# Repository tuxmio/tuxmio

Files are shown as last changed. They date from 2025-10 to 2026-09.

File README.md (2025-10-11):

## Hi there 👋
This project was started to combine industrial controllers, open-source controllers, and the freedom of customization.

1. Project Name & Description
   
    TUXMIO= 2XMIO=MIO+MIO=Make It Own Modular Input/Output System
TUXMIO is a customizable Modular Input/Output System. It allows users to mix and match hardware while keeping full control over their automation systems.

2. Features
   
    ✔ Modular Design – Easily expand and customize I/O modules based on project needs.
  
    ✔ Hybrid Compatibility – Works with both industrial controllers (PLC, DCS) and open-source hardware (Arduino, ESP32, Raspberry Pi).
  
    ✔ Cross-Platform Support – Works with Linux, Windows, and embedded systems.
  
    ✔ Industrial-Grade Reliability – Designed for rugged environments with robust protection features.
  
    ✔ Flexible Manufacturing Options – Users can build it themselves, order custom production, or buy pre-assembled modules.

3. Installation & Setup
   
    Hardware:
  
    ✔ Choose your favorite open-source controller
  
    ✔ Connect it to TUXMIO
  
    ✔ Enjoy your controller in an industrial environment
  
    Software & Setup:
  
    Use your usual tools for firmware installation, configuration, and testing—just like you always do!

4. Usage

    After setup, just start your system and enjoy your creation.

5. Hardware Requirements

    ✔ Choose your favorite open-source controller (Arduino, Raspberry Pi, ESP32, etc.).
   
    ✔ TUXMIO modules (customize based on your needs).
   
    ✔ You can prepare your own power supply voltages, or use the TUXMIO PS board for convenience.
   
    ✔ Any additional sensors, actuators, or peripherals based on your project.

6. Contributing

    Hey, I’m not a professional in electronics, 3D design, or prototyping, so please be understanding and forgiving if you spot any mistakes or discrepancies. 😊
   
    If you’d like to help out, here’s how you can contribute:
   
      ✔ Fork the Repo: Feel free to fork this repo and create a branch with your changes.
   
      ✔ Submit a Pull Request: When you're ready, send over a pull request!
   
      ✔ Report Issues: If you notice any bugs or have suggestions, don’t hesitate to open an issue.
   
      ✔ Join the Fun: Let’s work together to make this project better and take it to new heights!

7. License
   TUXMIO is proudly open in both mind and design.
All software and firmware are shared under the MIT License — free to use, modify, and remix however you like.
All hardware designs (schematics, PCBs, 3D models) follow the CERN Open Hardware License – Permissive v2.0, allowing you to build, improve, and even sell your own versions, as long as you keep the original attribution intact! 😊

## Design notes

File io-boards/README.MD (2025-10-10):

┌──────┬────────────┬───────────┬─────────────────────────────────────────────┬───────────────────────────────────────────────────────────────────────────────┐
│ Code │ Complexity │ Priority  │ Description                                 │ Notes                                                                         │
├──────┼────────────┼───────────┼─────────────────────────────────────────────┼───────────────────────────────────────────────────────────────────────────────┤
│ DI   │ 0          │ 1         │ Direct digital input (NPN/PNP stabilized)   │ Simple design, direct to MCU or buffer input.                                 │
│ DI   │ 4          │ -         │ Differential digital input (super-fast OC)  │ High-speed differential inputs, open-collector tolerant.                      │
│ DI   │ 2          │ -         │ Optocoupled digital input (NPN/PNP)         │ Isolated voltage sensing, moderate complexity.                                │
│ DO   │ 0          │ 1         │ Direct digital output (NPN/PNP stabilized)  │ Transistor-based output, low-side/high-side variants possible.                │
│ DO   │ 2          │ -         │ Optocoupled digital output (short-prot.)    │ Protected, diagnostic LEDs, block on short.                                   │
│ DO   │ 4          │ -         │ Super-fast optocoupled digital output       │ High-speed driver, isolation + diagnostics.                                   │
│ DO   │ 4          │ -         │ Differential digital output (OC)            │ Fast differential output, open-collector style.                               │
│ DO   │ 1          │ 2         │ Relay output                                │ Mechanical relay, user-changeable type.                                       │
│ DO   │ 1          │ 2         │ SSR relay output                            │ Solid State Relay variant.                                                    │
│ AI   │ 0          │ 1         │ Direct analog input 0–5V                    │ Basic ADC interface.                                                          │
│ AI   │ 1          │ -         │ 0–10V analog input                          │ Most common industrial input range.                                           │
│ AI   │ 2          │ -         │ ±10V analog input                           │ Bipolar measurement range.                                                    │
│ AI   │ 4          │ 5         │ 0–5mA analog input                          │ Requires precise current sensing, maybe external supply.                      │
│ AI   │ 4          │ 5         │ 0–20mA analog input                         │ Current loop sensing, possibly needs shunt resistor.                          │
│ AI   │ 4          │ 5         │ Low-voltage 0–10mV analog input             │ For small-signal sensors, instrumentation amp required.                       │
│ AI   │ 3          │ 5         │ Thermocouple input                          │ Requires CJC, precision ADC, low noise.                                       │
│ AI   │ 3          │ 5         │ RTD input (PT100/PT1000)                    │ Requires excitation and bridge measurement.                                   │
│ AO   │ 0          │ 1         │ Direct analog output 0–5V                   │ Simple DAC output.                                                            │
│ AO   │ 2          │ 2         │ 0–10V analog output                         │ Standard industrial output range.                                             │
│ AO   │ 2          │ 5         │ ±10V analog output                          │ Bipolar DAC driver, requires dual supply.                                     │
│ AO   │ 4          │ 3         │ 0–20mA analog output                        │ Current loop output, supply-dependent.                                        │
└──────┴────────────┴───────────┴─────────────────────────────────────────────┴───────────────────────────────────────────────────────────────────────────────┘

Enhanced I/O Function Table with ABC Codes
#	Old Code	New Code	Description	Notes / Feature keywords
1	DI	DID	Direct Digital Input (NPN/PNP stabilized)	simplest form, direct connection
2	DI	DIF	Differential Digital Input (superfast OC)	high-speed, open-collector compatible
3	DI	DIO	Optocoupled Digital Input (NPN/PNP voltage)	isolated, standard industrial input
4	DO	DOD	Direct Digital Output (NPN/PNP stabilized)	simple transistor output
5	DO	DOO	Optocoupled Digital Output (short-prot, diag)	isolated, protected, LED indicators
6	DO	DOF	Fast Optocoupled Digital Output (superfast)	high-speed variant
7	DO	DOH	Differential (High-speed OC) Digital Output	OC differential drivers
8	DO	DOR	Relay Output (mechanical relays)	changeable relay sockets
9	DO	DOS	SSR Output (Solid-State Relay)	solid-state version
10	AI	AIV	Analog Voltage Input (0–5V, 0–10V, ±10V)	voltage-based measurement
11	AI	AIC	Analog Current Input (0–5mA, 0–20mA)	current loop or shunt measurement
12	AI	AIL	Low-Voltage / Millivolt Input	instrumentation, low-noise sensors
13	AI	AIT	Thermocouple Input	temperature, requires CJC
14	AI	AIR	Resistance / RTD Input (PT100/PT1000)	with excitation and linearization
15	AO	AOV	Analog Voltage Output (0–5V, 0–10V, ±10V)	DAC-based voltage output
16	AO	AOC	Analog Current Output (0–20mA)	current loop output
17	COM	CCI	Communication Interface Input (e.g., RS, CAN)	receives data
18	COM	CCO	Communication Interface Output	transmits data
19	COM	CCX	Communication Transceiver / Bidirectional	bidirectional (e.g., RS485, CAN, I²C)

1st letter: Domain
D → Digital
A → Analog
C → Communication

2nd letter: Direction
I → Input
O → Output
X → Bidirectional / mixed

3rd letter: Feature

D = Direct
O = Optocoupled
F = Fast / Differential
R = Relay
S = Solid State
V = Voltage
C = Current
L = Low voltage / millivolt
T = Thermocouple
R = RTD (resistance sensor)
H = High-speed / OC
X = Mixed / special

┌────────────┬───────────┬───────────────────────────────────────────────┐
│ Letter Pos │ Represents│ Example Letters / Meaning                     │
├────────────┼───────────┼───────────────────────────────────────────────┤
│ 1st        │ Domain    │ D = Digital, A = Analog, C = Communication    │
│ 2nd        │ Direction │ I = Input, O = Output, X = Bidirectional      │
│ 3rd        │ Feature   │ D = Direct, O = Optocoupled, F = Fast,        │
│            │           │ R = Relay, S = Solid-state, V = Voltage,      │
│            │           │ C = Current, L = Low-voltage, T = TC, R = RTD │
└────────────┴───────────┴───────────────────────────────────────────────┘

<ABC>-<LS>-<PT>-<RPO>-Vx.xx

where:
ABC = 3-letter functional code = [Domain][Direction][Feature]
    Domain: A = Analog, D = Digital (use “Digital”), C = Communication
    Direction: I = Input, O = Output, X = Bidirectional
    Feature: domain-specific (e.g. D=Direct, O=Optocoupled, F=Fast/Differential, R=Relay, S=SolidState, V=Voltage, C=Current, L=Low-voltage, T=Thermocouple, R=RTD, H=High-speed, X=Mixed)
LS = two digits: [LogicLevel][SocketType]
    LogicLevel (first digit): 3 = 3.3 V logic, 5 = 5 V logic, 9 = Mixed/Auto/Dual
    SocketType (second digit): 0 = Socket A, 1 = Socket B, 2 = Socket C, 3 = Socket D
PT = Peripheral Type (single letter)
    U = Voltage-type peripheral
    C = Current-type peripheral
RPO = Range code + Peripheral Option (two chars)
Range code (digit): Voltage codes (for U)
    0 = sink-mode NPN (logic sink)
    1 = 3.3/5 V logic-level field
    2 = 10 V
    3 = 12 V
    4 = 15 V
    5 = 24 V
    6 = 230 VAC
Range code (digit): Current codes (for C)
    0 = 0–5 mA
    1 = 0–20 mA
    2 = 4–20 mA
    3 = −20 mA … +20 mA
Peripheral Option (letter, immediately after range digit):
    N = Sink mode (NPN)
    P = Source mode (PNP)
    B = Bipolar
Vx.xx = Version (major.minor) e.g. V0.01

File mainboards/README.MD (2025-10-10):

TUXMIO Mainboard Classification
┌──────────────┬──────────────────────────────┬────────┬──────────────────────────────────────────────────────────────────────────────┐
│ Directory    │ Full Name                    │ Level  │ Description                                                                  │
├──────────────┼──────────────────────────────┼────────┼──────────────────────────────────────────────────────────────────────────────┤
│ L0-MB-PML    │ Power Management Layer       │ L0     │ Handles power entry, conversion, and protection (fuse, surge, polarity).     │
│              │                              │        │ Supplies regulated voltages to upper layers.                                 │
├──────────────┼──────────────────────────────┼────────┼──────────────────────────────────────────────────────────────────────────────┤
│ L1-MB-CIM    │ Controller Interface Module  │ L1     │ Hosts the main controller (MCU, SBC, or SoM). Manages logic, communication   │
│              │                              │        │ and links between the power and I/O layers.                                  │
├──────────────┼──────────────────────────────┼────────┼──────────────────────────────────────────────────────────────────────────────┤
│ L2-MB-IOP    │ Input/Output Peripherals     │ L2     │ Provides interface for I/O boards, sensors, and actuators. Includes sockets  │
│              │                              │        │ for I/O boards. each socket only supports specific I/O board types           │
└──────────────┴──────────────────────────────┴────────┴──────────────────────────────────────────────────────────────────────────────┘
 
   ┌┐   ┌┐   ┌┐   ┌┐   ┌┐   ┌┐   ┌┐   
   ||   ||   ||   ||   ||   ||   ||
   ||   ||   ||   ||   ||   ||   ||  ← I/O Boards
   ||   ||   ||   ||   ||   ||   ||
   └┘   └┘   └┘   └┘   └┘   └┘   └┘   
   ┌──────────────────────────────┐
   │  L2 – MB-IOP  (Peripherals)  │  ← I/O Expansion Layer
   └─────────────┬────────────────┘
                 │
   ┌─────────────┴────────────────┐
   │  L1 – MB-CIM  (Controller)   │  ← Processing & Communication Layer
   └─────────────┬────────────────┘
                 │
   ┌─────────────┴────────────────┐
   │  L0 – MB-PML  (Power)        │  ← Power & Protection Base Layer
   └──────────────────────────────┘

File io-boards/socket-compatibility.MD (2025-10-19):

Socket–Board compatibility is non-commutative.

> a board designed for Socket A may fit Socket B, but not necessarily vice-versa.

Final (refined) socket acronyms
#	Acronym	   Cards        Full Name	            Description
0	GPP	       DI/DO/AO     General Purpose Pin	    Multi-use socket — supports digital input/output and analog output. Default I/O connection.
1	AIP	       AI           Analog Input Pin	    Dedicated analog input socket for sensors (voltage, current, RTD, etc.).
2	URP	       Serial COM   UART Pin	            Serial communication socket — TX/RX pair for asynchronous data.
3	ICP	       I²C          I²C Pin	                Two-wire serial communication socket — SCL/SDA lines for intelligent peripherals.

Compatibility Matrix
┌───────────────┬─────┬─────┬─────┬─────┐
│ Board \ Socket│ GPP │ AIP │ URP │ ICP │
├───────────────┼─────┼─────┼─────┼─────┤
│ GPP           │  ✓  │  ✓  │  ✓  │  ✓  │
│ AIP           │     │  ✓  │     │  ✓  │
│ URP           │     │     │  ✓  │     │
│ ICP           │     │     │     │  ✓  │
└───────────────┴─────┴─────┴─────┴─────┘

🧩 Physical Connection System

All TUXMIO sockets and boards use 2.54 mm pitch pin header–type connectors for electrical and mechanical connection.
Sockets are equipped with female pin headers, while the I/O boards use corresponding male pin headers.
To ensure correct insertion and prevent incompatible combinations, certain holes in the socket connectors are mechanically blocked using plastic plugs, and matching pins are omitted on the corresponding boards.
This selective pin arrangement allows each board to fit only into its appropriate socket type, maintaining both electrical safety and system integrity.
Additionally, all connectors are polarized — boards cannot be inserted rotated 180°, preventing reverse connection or damage to components.For detailed socket–board relationships, For detailed socket–board relationships, please see the compatibility matrix.

Legend (for the table)
Sockets: o = empty hole, x = plugged hole
I/O Boards: - = pin present, x = pin absent

┌────────────┬───────────────────────┬───────────────────────────┬───────────────────────────┐
│            │                       │         Sockets           │        I/O Boards         │
│ Pin Number │ Function              ├──────┬──────┬──────┬──────┼──────┬──────┬──────┬──────┤
│            │                       │ GPP  │ AIP  │ URP  │ ICP  │ GPP  │ AIP  │ URP  │ ICP  │
├────────────┼───────────────────────┼──────┼──────┼──────┼──────┼──────┼──────┼──────┼──────┤
│ 1          │ IO pin to uC          │ o    │ o    │ o    │ o    │  -   │  -   │  -   │  -   │IO
│ 2          │ A_REF pin from uC     │ x    │ o    │ x    │ o    │  x   │  -   │  x   │  -   │A_Ref
│ 3          │ GND or GND1(seperated)│ o    │ o    │ o    │ o    │  -   │  -   │  -   │  -   │GND1
│ 4          │ N/A                   │ o    │ x    │ o    │ o    │  x   │  x   │  -   │  -   │N/A
│ 5          │ Diagnostics for future│ o    │ o    │ o    │ o    │  -   │  -   │  -   │  -   │Diag
│ 6          │ -10V bipolar          │ o    │ o    │ o    │ o    │  -   │  -   │  -   │  -   │-10V_b
│ 7          │   OV bipolar          │ o    │ o    │ o    │ o    │  -   │  -   │  -   │  -   │0V_b
│ 8          │ +10V bipolar          │ o    │ o    │ o    │ o    │  -   │  -   │  -   │  -   │+10V_b
│ 9          │ Not assigned yet      │ o    │ o    │ o    │ o    │  -   │  -   │  -   │  -   │N/A_Pin_9
│ 10         │ N/A                   │ x    │ x    │ o    │ x    │  x   │  x   │  -   │  x   │N/A
│ 11         │ +24VDC                │ o    │ o    │ o    │ o    │  -   │  -   │  -   │  -   │+24VDC
│ 12         │ GND from 24V          │ o    │ o    │ o    │ o    │  -   │  -   │  -   │  -   │GND_24V
└────────────┴───────────────────────┴──────┴──────┴──────┴──────┴──────┴──────┴──────┴──────┘

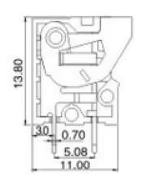
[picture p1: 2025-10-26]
accessories/Cover_for_terminal_KF141/KF141V.png

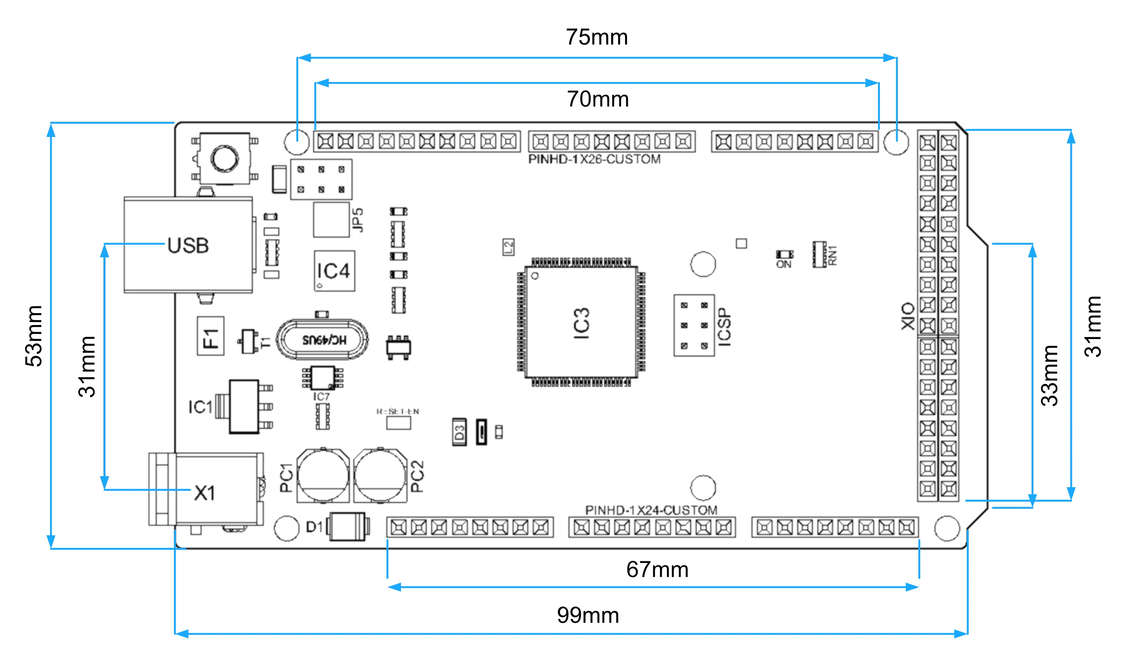
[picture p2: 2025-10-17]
datasheets/third-part/mega2560_dimmentions.png

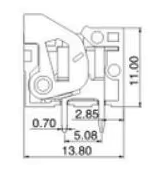
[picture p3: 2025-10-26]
accessories/Cover_for_terminal_KF141/KF141R.png

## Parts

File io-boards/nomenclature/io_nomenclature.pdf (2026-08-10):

Sheet1

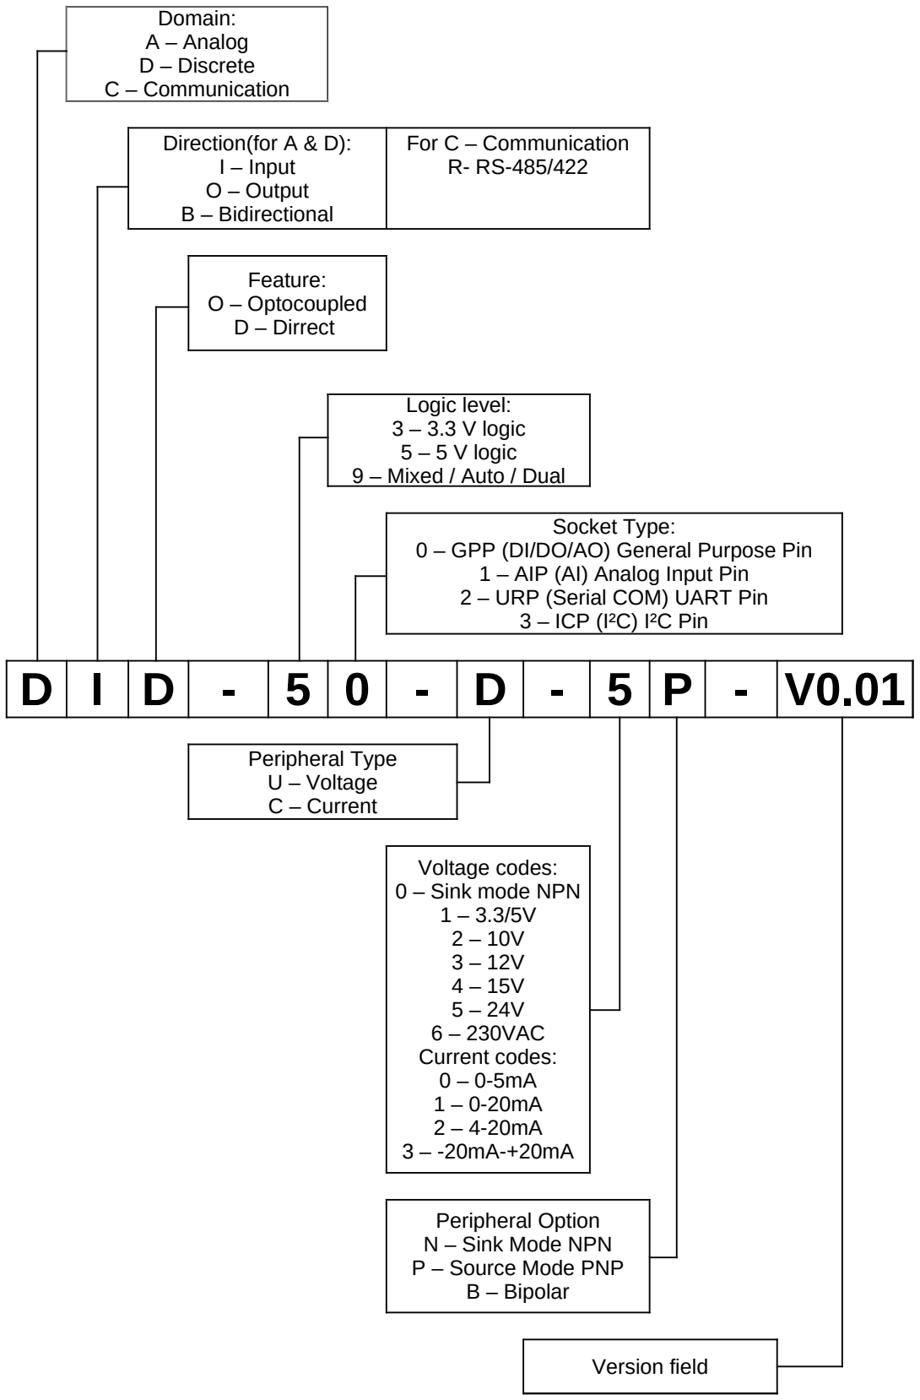
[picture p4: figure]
Version field; Domain: A – Analog D – Discrete C – Communication; Direction(for A & D): I – Input O – Output B – Bidirectional; For C – Communication R- RS-485/422; Feature: O – Optocoupled D – Dirrect; Logic level: 3 – 3.3 V logic 5 – 5 V logic 9 – Mixed / Auto / Dual; Socket Type: 0 – GPP (DI/DO/AO) General Purpose Pin 1 – AIP (AI) Analog Input Pin 2 – URP (Serial COM) UART Pin 3 – ICP (I²C) I²C Pin; Peripheral Type U – Voltage C – Current; Voltage codes: 0 – Sink mode NPN 1 – 3.3/5V 2 – 10V 3 – 12V 4 – 15V 5 – 24V 6 – 230VAC Current codes: 0 – 0-5mA 1 – 0-20mA 2 – 4-20mA 3 – -20mA-+20mA; Peripheral Option N – Sink Mode NPN P – Source Mode PNP B – Bipolar

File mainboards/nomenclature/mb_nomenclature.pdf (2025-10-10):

Sheet1

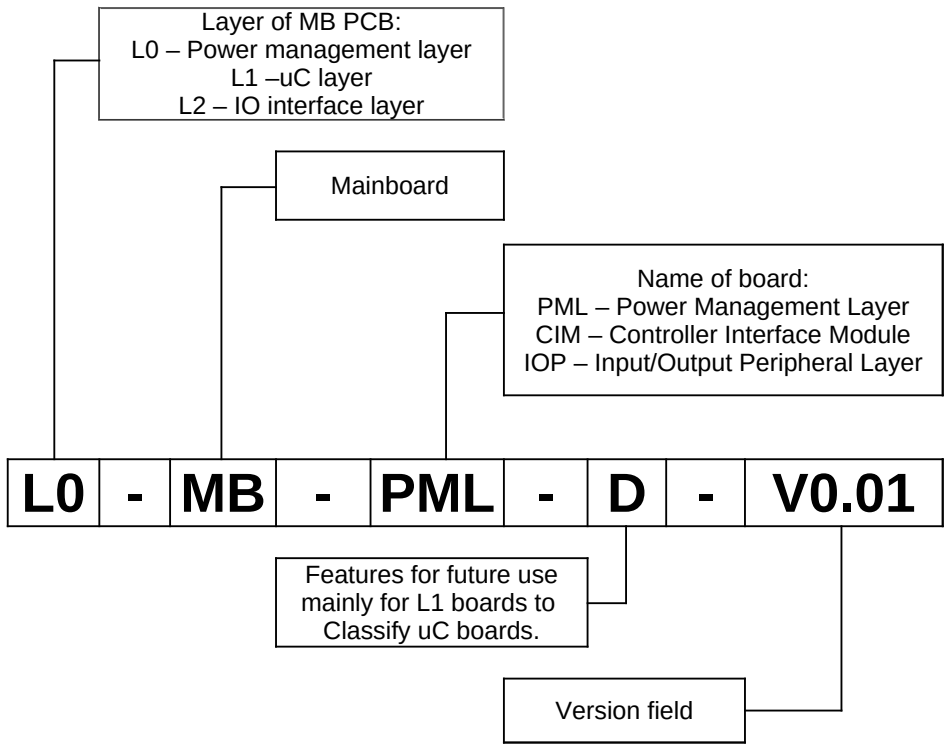
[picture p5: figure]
Mainboard; PML; Version field; Layer of MB PCB: L0 – Power management layer L1 –uC layer L2 – IO interface layer; Name of board: PML – Power Management Layer CIM – Controller Interface Module IOP – Input/Output Peripheral Layer; Features for future use mainly for L1 boards to Classify uC boards.

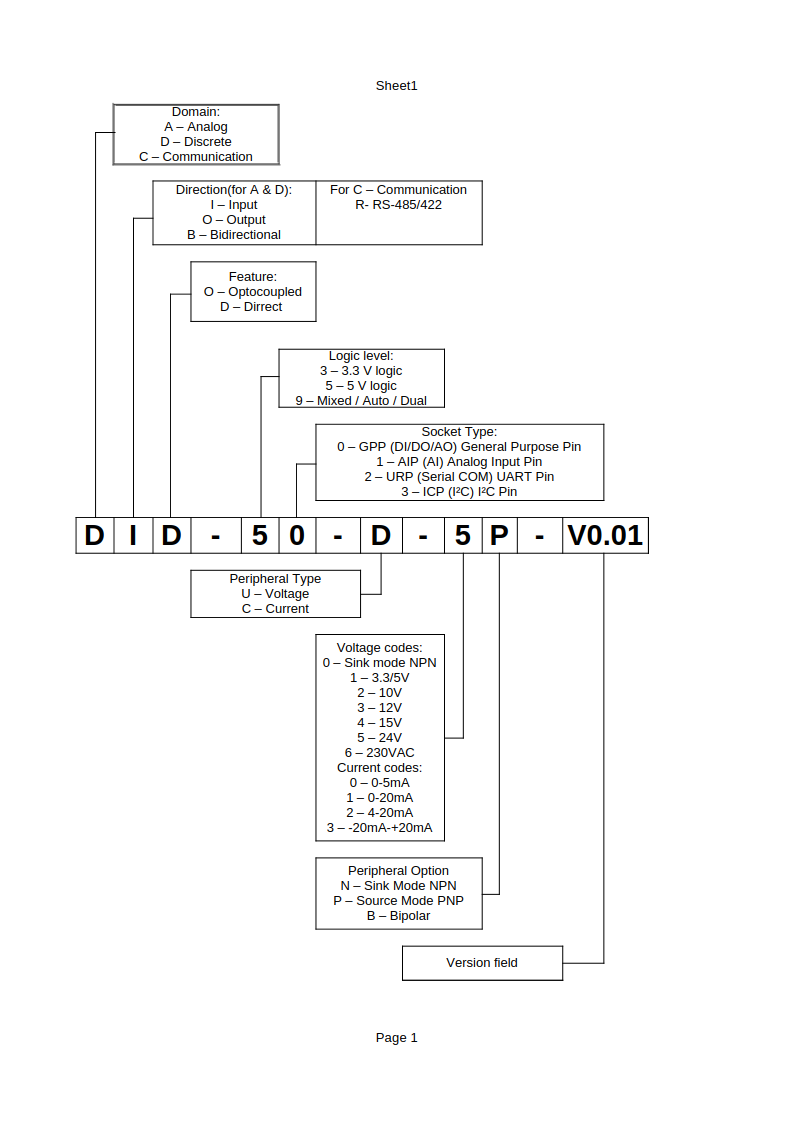
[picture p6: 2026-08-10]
io-boards/nomenclature/io_nomenclature.png

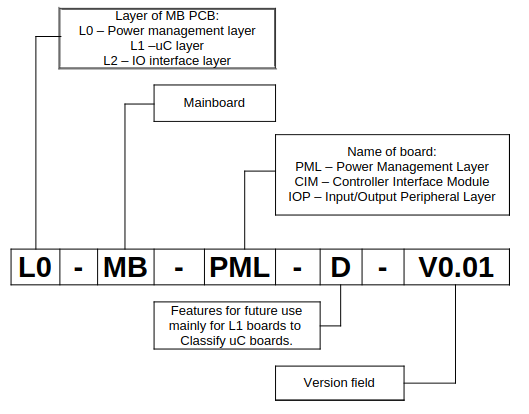
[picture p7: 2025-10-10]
mainboards/nomenclature/mb_nomenclature.png

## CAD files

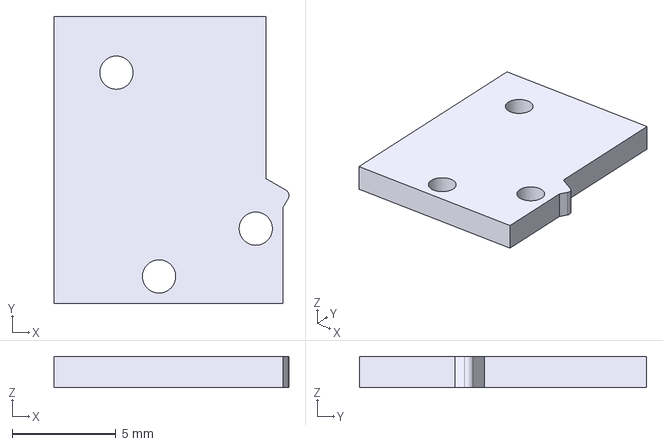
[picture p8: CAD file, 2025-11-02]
accessories/Cover_for_terminal_KF141/KF141_Cover.step
11.3 x 13.8 x 1.50 mm

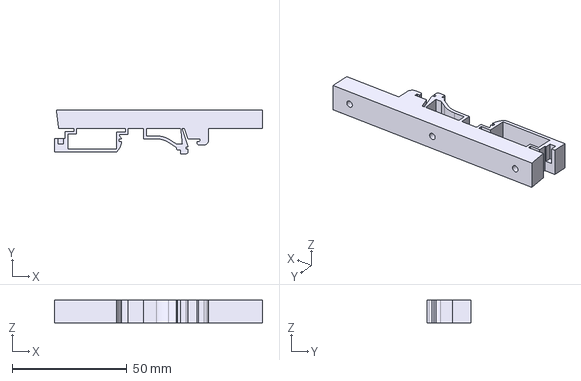
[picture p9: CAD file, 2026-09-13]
accessories/DIN_rail_PCB_adapter/PCB-adapter-90-edited-Body.step
90.8 x 19.0 x 10.0 mm

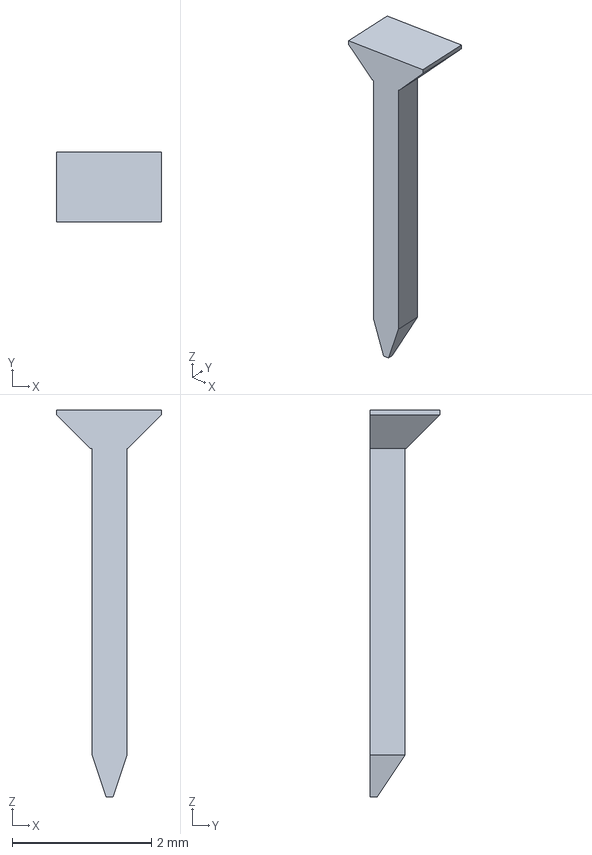
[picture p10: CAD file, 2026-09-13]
accessories/Pin_Plug/Plug.FCStd
1.50 x 1.00 x 5.55 mm

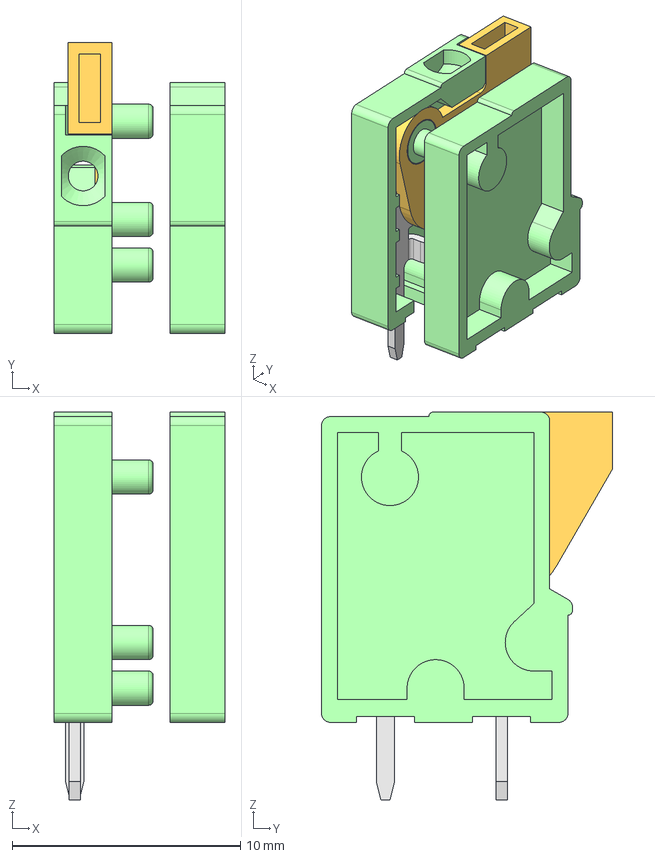
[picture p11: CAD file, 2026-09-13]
datasheets/third-part/FFKDS_V.FCStd
7.48 x 12.8 x 17.0 mm
Body(Cut)
Lever
Pin
EndPlate

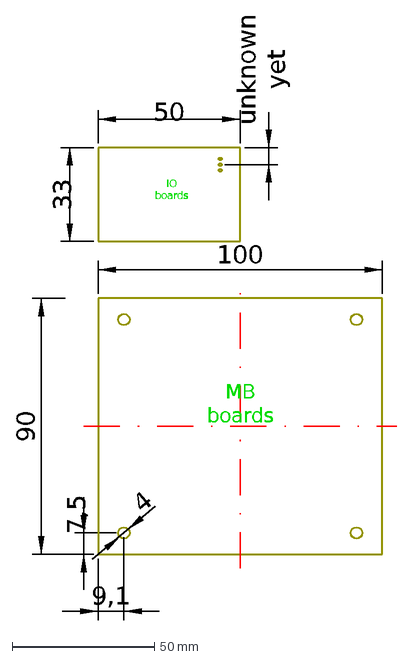
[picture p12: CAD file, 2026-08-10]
datasheets/tuxmio/Dimentions_of_boards.dxf
7,5
33
50
IO boards
unknown yet
100
4
9,1
90
MB boards

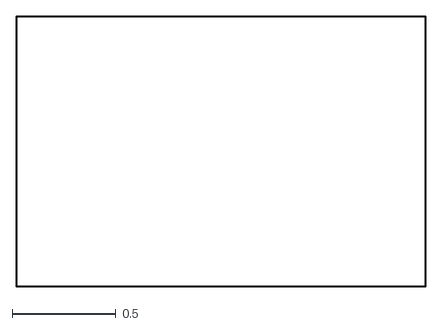
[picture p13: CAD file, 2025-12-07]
io-boards/DI/DIO-50-U-5B/DIO-50-U-5B-Edge_Cuts.dxf
1.97 x 1.30

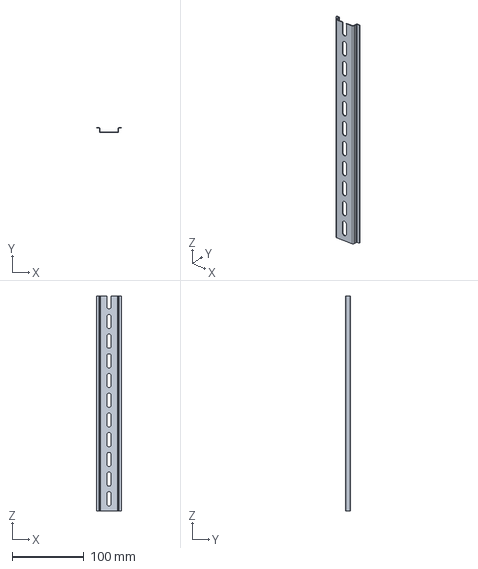
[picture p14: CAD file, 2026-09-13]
accessories/DIN_rail_PCB_adapter/DIN-rail.FCStd
35.0 x 7.50 x 300.0 mm

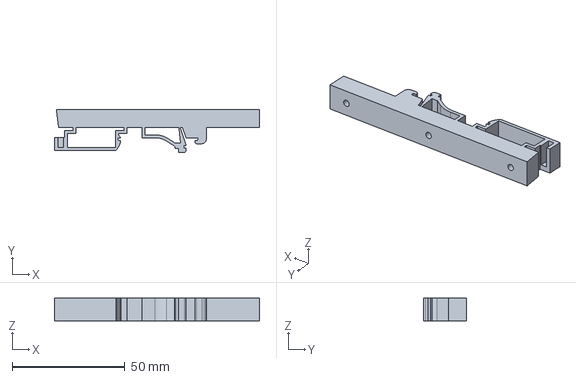
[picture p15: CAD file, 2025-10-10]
accessories/DIN_rail_PCB_adapter/PCB-adapter-90.FCStd
90.8 x 19.0 x 10.0 mm

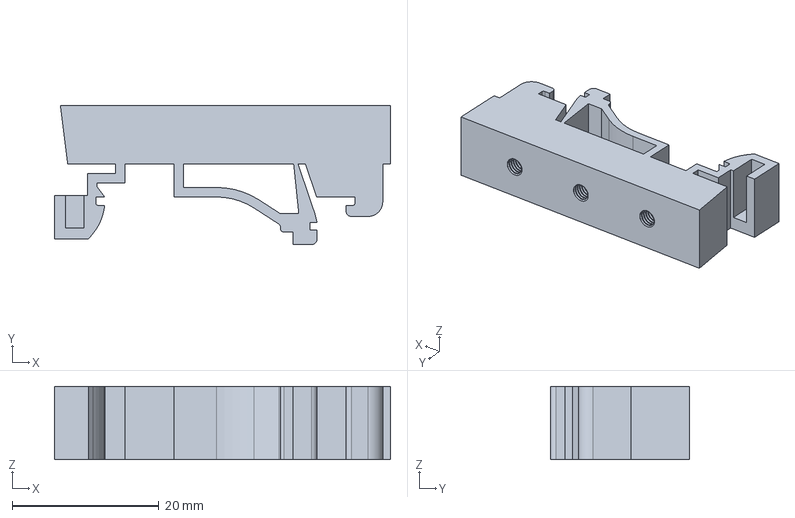
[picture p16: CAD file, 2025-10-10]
accessories/DIN_rail_PCB_adapter/PCB-adapter-45.FCStd
45.8 x 19.0 x 10.0 mm

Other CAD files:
accessories/Cover_for_terminal_KF141/cover-CoverPad.stl
accessories/Pin_Plug/Plug-Body.step
accessories/Cover_for_terminal_KF141/cover.FCStd
accessories/DIN_rail_PCB_adapter/PCB-adapter-90-edited.FCStd
accessories/DIN_rail_PCB_adapter/PCB-adapter-45.stl
accessories/DIN_rail_PCB_adapter/PCB-adapter-90.stl
io-boards/DI/DIO-50-U-5B/DIO-50-U-5B-F_Silkscreen.dxf

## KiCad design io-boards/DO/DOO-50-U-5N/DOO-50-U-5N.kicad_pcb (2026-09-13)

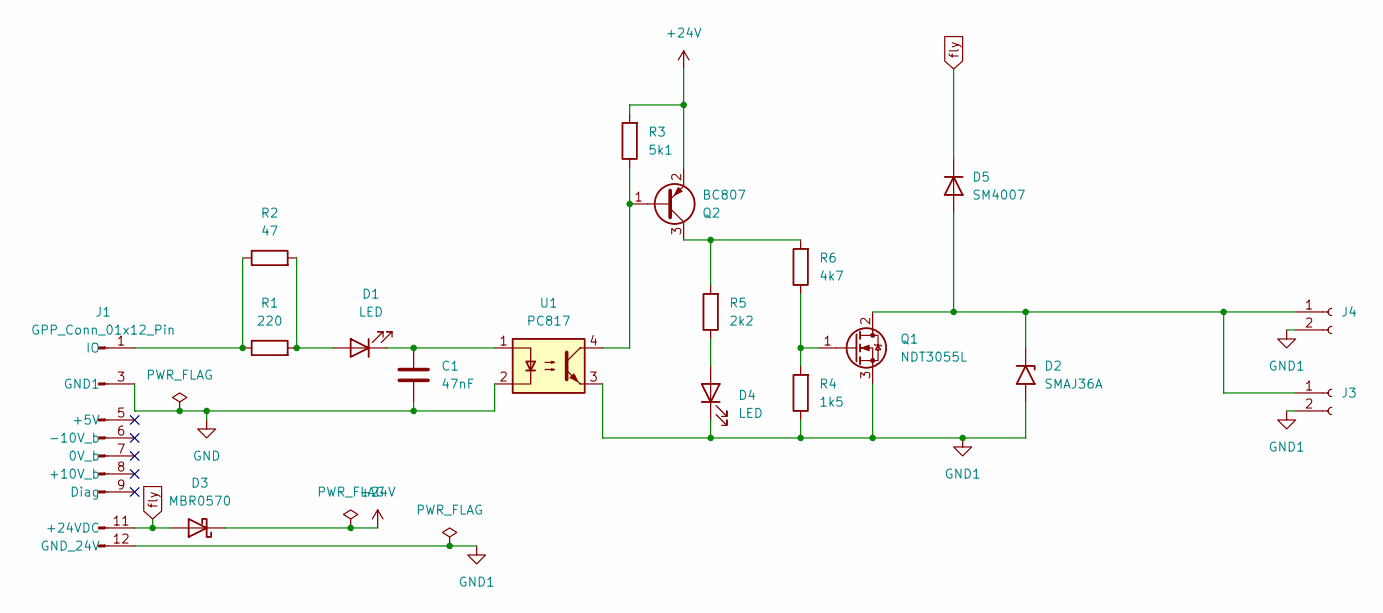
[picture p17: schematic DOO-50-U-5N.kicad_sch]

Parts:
C1: 47nF; C_0201_0603Metric
D1, D4: LED; LED_0402_1005Metric_Pad0.77x0.64mm_HandSolder
D2: SMAJ36A; D_SMA
D3: MBR0570; D_SOD-123
D5: SM4007; D_MELF_Handsoldering
J1: GPP_Conn_01x12_Pin; IO_GPP_PinHeader_1x12_P2.54mm_Horizontal
J3: Conn_01x02_Socket; KF141x_SMD
J4: Conn_01x02_Socket; PinSocket_1x02_P2.54mm_Horizontal
Q1: NDT3055L; SOT-223-3_TabPin2
Q2: BC807; SOT-23
R1: 220; R_0402_1005Metric_Pad0.72x0.64mm_HandSolder
R2: 47; R_0402_1005Metric_Pad0.72x0.64mm_HandSolder
R3: 5k1; R_0402_1005Metric_Pad0.72x0.64mm_HandSolder
R4: 1k5; R_0402_1005Metric_Pad0.72x0.64mm_HandSolder
R5: 2k2; R_0402_1005Metric_Pad0.72x0.64mm_HandSolder
R6: 4k7; R_0402_1005Metric_Pad0.72x0.64mm_HandSolder
U1: PC817; DIP-4_W7.62mm_SMDSocket_SmallPads

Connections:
+24V: D3.1 (K), Q2.2 (E), R3.2
GND: C1.2, J1.3 (GND1), U1.2
GND1: D2.2 (A2), D4.1 (K), J1.12 (GND_24V), J3.2, J4.2, Q1.3 (S), R4.1, U1.3
unnamed: D1.2 (A), R1.2, R2.2
unnamed: C1.1, D1.1 (K), U1.1
unnamed: D2.1 (A1), D5.2 (A), J3.1, J4.1, Q1.2 (D)
unnamed: D4.2 (A), R5.1
unnamed: J1.1 (IO), R1.1, R2.1
unnamed: Q1.1 (G), R4.2, R6.1
unnamed: Q2.1 (B), R3.1, U1.4
unnamed: Q2.3 (C), R5.2, R6.2
fly: D3.2 (A), D5.1 (K), J1.11 (+24VDC)

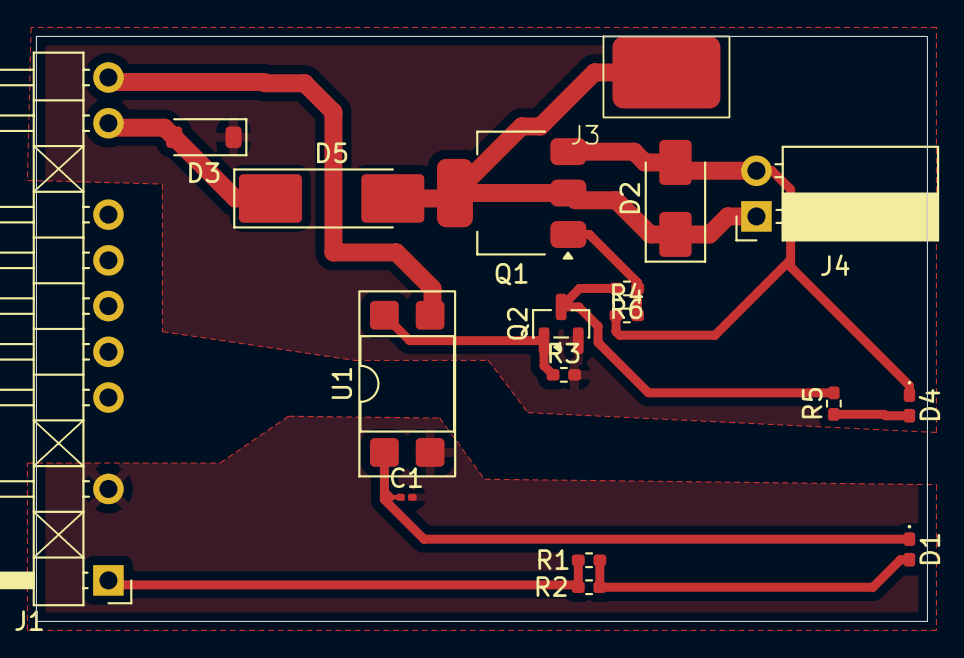
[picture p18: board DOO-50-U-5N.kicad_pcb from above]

Board: 2 copper layers, 49.5 x 32.5 mm, 18 parts (0 on the bottom side), 12 nets.

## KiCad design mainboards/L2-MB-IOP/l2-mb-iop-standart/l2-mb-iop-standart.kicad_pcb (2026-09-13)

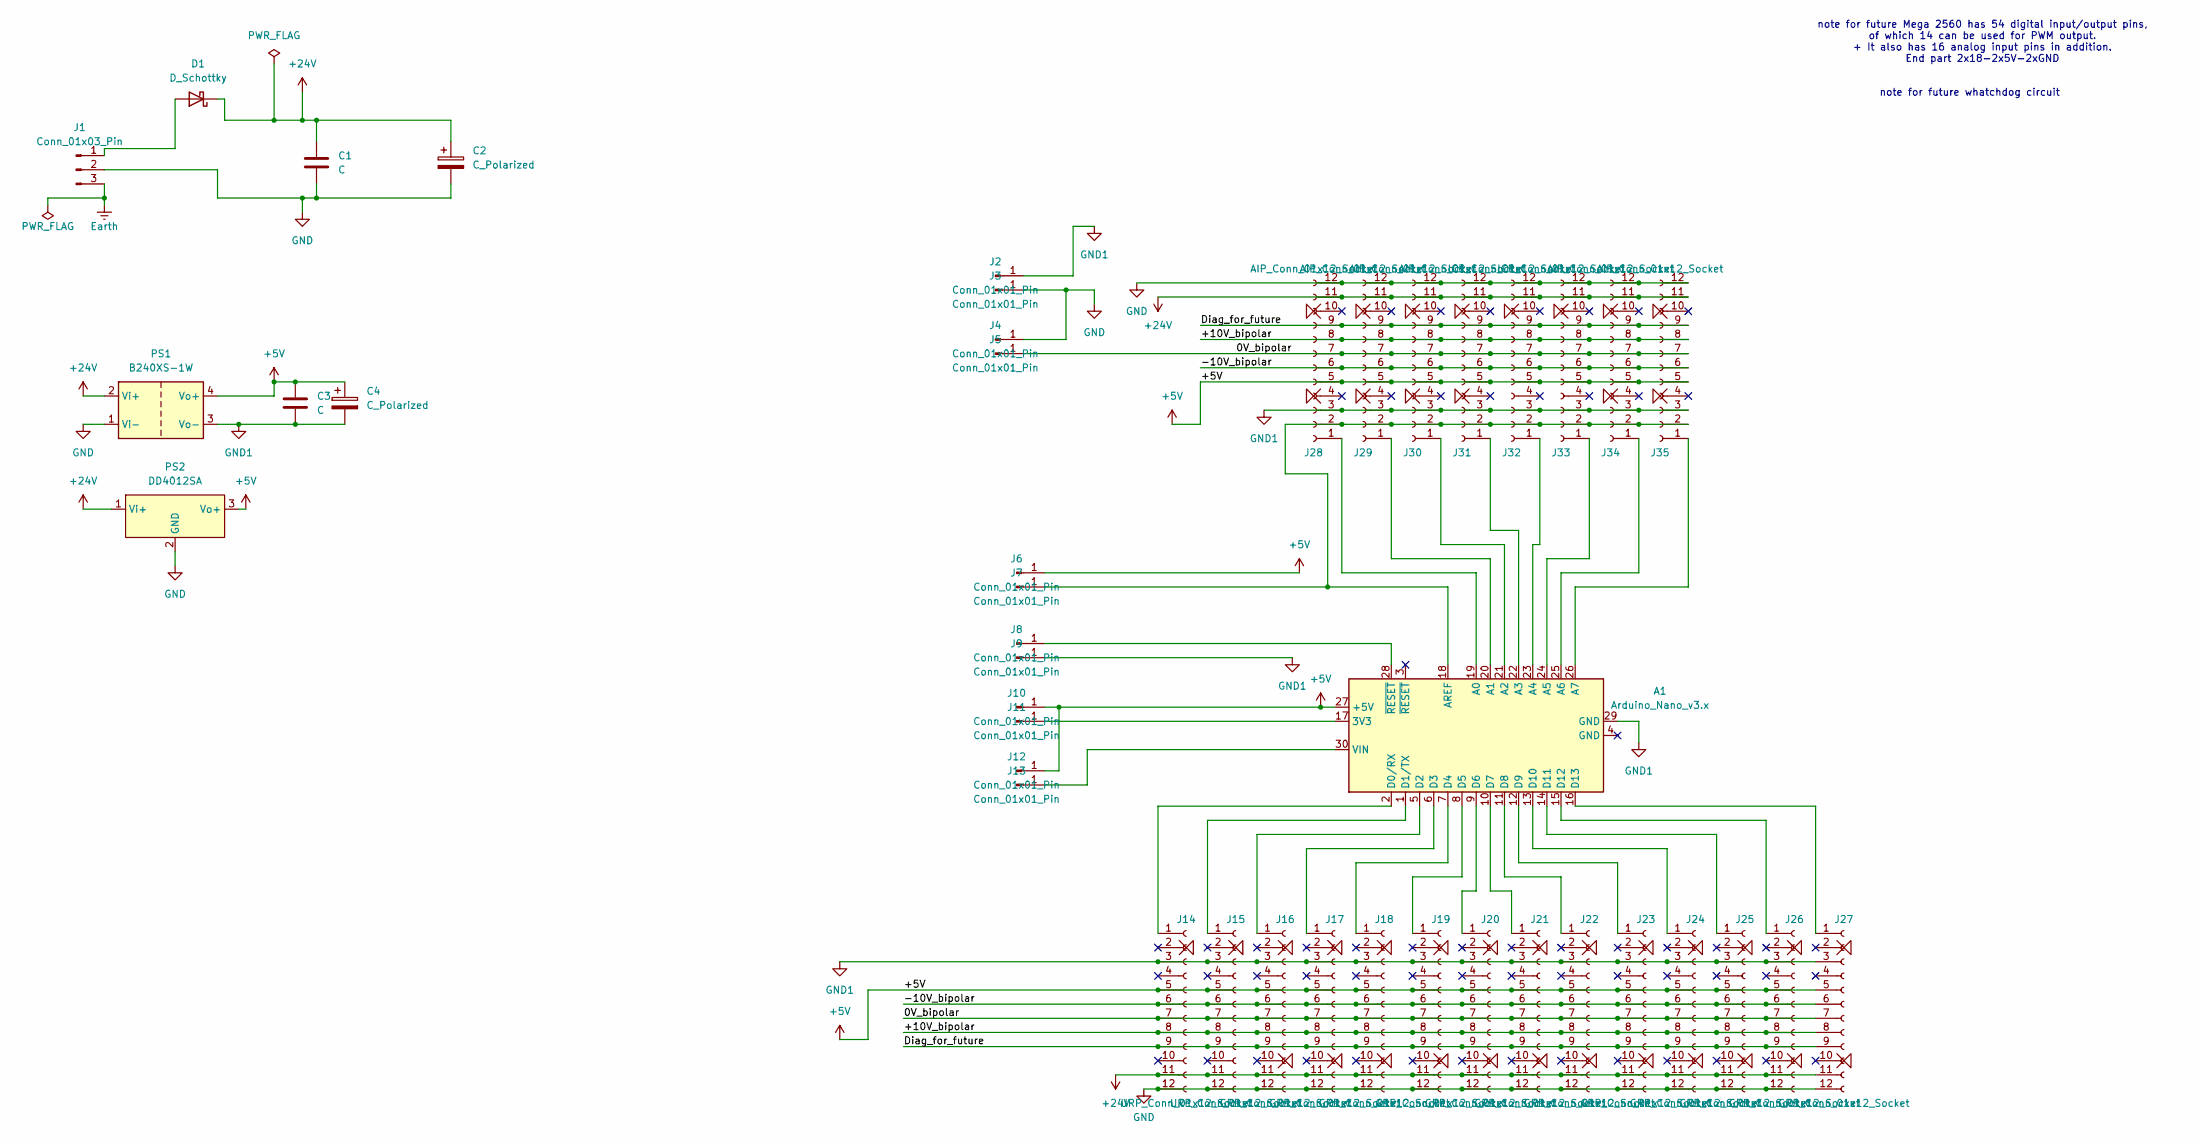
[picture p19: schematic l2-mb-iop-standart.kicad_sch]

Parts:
A1: Arduino_Nano_v3.x; Arduino_Nano
C1, C3: C
C2, C4: C_Polarized
D1: D_Schottky
J1: Conn_01x03_Pin
J2, J3, J4, J5, J6, J7, J8, J9, J10, J11, J12, J13: Conn_01x01_Pin
J14, J15: URP_Conn_01x12_Socket; MB_URP_PinSocket_1x12_P2.54mm_Vertical
J16, J17, J18, J19, J20, J21, J22, J23, J24, J25, J26, J27: GPP_Conn_01x12_Socket; MB_GPP_PinSocket_1x12_P2.54mm_Vertical
J28, J29, J30, J31, J34, J35: AIP_Conn_01x12_Socket; MB_AIP_PinSocket_1x12_P2.54mm_Vertical
J32, J33: ICP_Conn_01x12_Socket; MB_ICP_PinSocket_1x12_P2.54mm_Vertical
PS1: B240XS-1W
PS2: DD4012SA

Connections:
+5V: A1.27 (+5V), C3.1, C4.1, J6.1, J10.1, J12.1, J14.5 (Diag), J15.5 (Diag), J16.5 (Diag), J17.5 (Diag), J18.5 (Diag), J19.5 (Diag), J20.5 (Diag), J21.5 (Diag), J22.5 (Diag), J23.5 (Diag), J24.5 (Diag), J25.5 (Diag), J26.5 (Diag), J27.5 (Diag), J28.5 (Diag), J29.5 (Diag), J30.5 (Diag), J31.5 (Diag), J32.5 (Diag), J33.5 (Diag), J34.5 (Diag), J35.5 (Diag), PS1.4 (Vo+), PS2.3 (Vo+)
+24V: C1.1, C2.1, D1.1 (K), J14.11 (+24VDC), J15.11 (+24VDC), J16.11 (+24VDC), J17.11 (+24VDC), J18.11 (+24VDC), J19.11 (+24VDC), J20.11 (+24VDC), J21.11 (+24VDC), J22.11 (+24VDC), J23.11 (+24VDC), J24.11 (+24VDC), J25.11 (+24VDC), J26.11 (+24VDC), J27.11 (+24VDC), J28.11 (+24VDC), J29.11 (+24VDC), J30.11 (+24VDC), J31.11 (+24VDC), J32.11 (+24VDC), J33.11 (+24VDC), J34.11 (+24VDC), J35.11 (+24VDC), PS1.2 (Vi+), PS2.1 (Vi+)
/0V_bipolar: J5.1, J14.7 (0V_b), J15.7 (0V_b), J16.7 (0V_b), J17.7 (0V_b), J18.7 (0V_b), J19.7 (0V_b), J20.7 (0V_b), J21.7 (0V_b), J22.7 (0V_b), J23.7 (0V_b), J24.7 (0V_b), J25.7 (0V_b), J26.7 (0V_b), J27.7 (0V_b), J28.7 (0V_b), J29.7 (0V_b), J30.7 (0V_b), J31.7 (0V_b), J32.7 (0V_b), J33.7 (0V_b), J34.7 (0V_b), J35.7 (0V_b)
/+10V_bipolar: J14.8 (+10V_b), J15.8 (+10V_b), J16.8 (+10V_b), J17.8 (+10V_b), J18.8 (+10V_b), J19.8 (+10V_b), J20.8 (+10V_b), J21.8 (+10V_b), J22.8 (+10V_b), J23.8 (+10V_b), J24.8 (+10V_b), J25.8 (+10V_b), J26.8 (+10V_b), J27.8 (+10V_b), J28.8 (+10V_b), J29.8 (+10V_b), J30.8 (+10V_b), J31.8 (+10V_b), J32.8 (+10V_b), J33.8 (+10V_b), J34.8 (+10V_b), J35.8 (+10V_b)
/-10V_bipolar: J14.6 (-10V_b), J15.6 (-10V_b), J16.6 (-10V_b), J17.6 (-10V_b), J18.6 (-10V_b), J19.6 (-10V_b), J20.6 (-10V_b), J21.6 (-10V_b), J22.6 (-10V_b), J23.6 (-10V_b), J24.6 (-10V_b), J25.6 (-10V_b), J26.6 (-10V_b), J27.6 (-10V_b), J28.6 (-10V_b), J29.6 (-10V_b), J30.6 (-10V_b), J31.6 (-10V_b), J32.6 (-10V_b), J33.6 (-10V_b), J34.6 (-10V_b), J35.6 (-10V_b)
/Diag_for_future: J14.9 (N/A_Pin_9), J15.9 (N/A_Pin_9), J16.9 (N/A_Pin_9), J17.9 (N/A_Pin_9), J18.9 (N/A_Pin_9), J19.9 (N/A_Pin_9), J20.9 (N/A_Pin_9), J21.9 (N/A_Pin_9), J22.9 (N/A_Pin_9), J23.9 (N/A_Pin_9), J24.9 (N/A_Pin_9), J25.9 (N/A_Pin_9), J26.9 (N/A_Pin_9), J27.9 (N/A_Pin_9), J28.9 (N/A_Pin_9), J29.9 (N/A_Pin_9), J30.9 (N/A_Pin_9), J31.9 (N/A_Pin_9), J32.9 (N/A_Pin_9), J33.9 (N/A_Pin_9), J34.9 (N/A_Pin_9), J35.9 (N/A_Pin_9)
Earth: J1.3
GND: C1.2, C2.2, J1.2, J3.1, J4.1, J14.12 (GND_24V), J15.12 (GND_24V), J16.12 (GND_24V), J17.12 (GND_24V), J18.12 (GND_24V), J19.12 (GND_24V), J20.12 (GND_24V), J21.12 (GND_24V), J22.12 (GND_24V), J23.12 (GND_24V), J24.12 (GND_24V), J25.12 (GND_24V), J26.12 (GND_24V), J27.12 (GND_24V), J28.12 (GND_24V), J29.12 (GND_24V), J30.12 (GND_24V), J31.12 (GND_24V), J32.12 (GND_24V), J33.12 (GND_24V), J34.12 (GND_24V), J35.12 (GND_24V), PS1.1 (Vi-), PS2.2 (GND)
GND1: A1.29 (GND), C3.2, C4.2, J2.1, J9.1, J14.3 (GND1), J15.3 (GND1), J16.3 (GND1), J17.3 (GND1), J18.3 (GND1), J19.3 (GND1), J20.3 (GND1), J21.3 (GND1), J22.3 (GND1), J23.3 (GND1), J24.3 (GND1), J25.3 (GND1), J26.3 (GND1), J27.3 (GND1), J28.3 (GND1), J29.3 (GND1), J30.3 (GND1), J31.3 (GND1), J32.3 (GND1), J33.3 (GND1), J34.3 (GND1), J35.3 (GND1), PS1.3 (Vo-)
unnamed: A1.17 (3V3), J11.1
unnamed: A1.19 (A0), J28.1 (IO)
unnamed: A1.20 (A1), J29.1 (IO)
unnamed: A1.21 (A2), J30.1 (IO)
unnamed: A1.22 (A3), J31.1 (IO)
unnamed: A1.23 (A4), J32.1 (IO)
unnamed: A1.24 (A5), J33.1 (IO)
unnamed: A1.25 (A6), J34.1 (IO)
unnamed: A1.26 (A7), J35.1 (IO)
unnamed: A1.18 (AREF), J7.1, J28.2 (A_Ref), J29.2 (A_Ref), J30.2 (A_Ref), J31.2 (A_Ref), J32.2 (A_Ref), J33.2 (A_Ref), J34.2 (A_Ref), J35.2 (A_Ref)
unnamed: A1.2 (D0/RX), J14.1 (IO)
unnamed: A1.1 (D1/TX), J15.1 (IO)
unnamed: A1.5 (D2), J16.1 (IO)
unnamed: A1.6 (D3), J17.1 (IO)
unnamed: A1.7 (D4), J18.1 (IO)
unnamed: A1.8 (D5), J19.1 (IO)
unnamed: A1.9 (D6), J20.1 (IO)
unnamed: A1.10 (D7), J21.1 (IO)
unnamed: A1.11 (D8), J22.1 (IO)
unnamed: A1.12 (D9), J23.1 (IO)
unnamed: A1.13 (D10), J24.1 (IO)
unnamed: A1.14 (D11), J25.1 (IO)
unnamed: A1.15 (D12), J26.1 (IO)
unnamed: A1.16 (D13), J27.1 (IO)
unnamed: A1.30 (VIN), J13.1
unnamed: D1.2 (A), J1.1
unnamed: A1.28 (~RESET), J8.1

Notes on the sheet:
note for future Mega 2560 has 54 digital input/output pins, of which 14 can be used for PWM output. + It also has 16 analog input pins in addition. End part 2x18-2x5V-2xGND
note for future whatchdog circuit

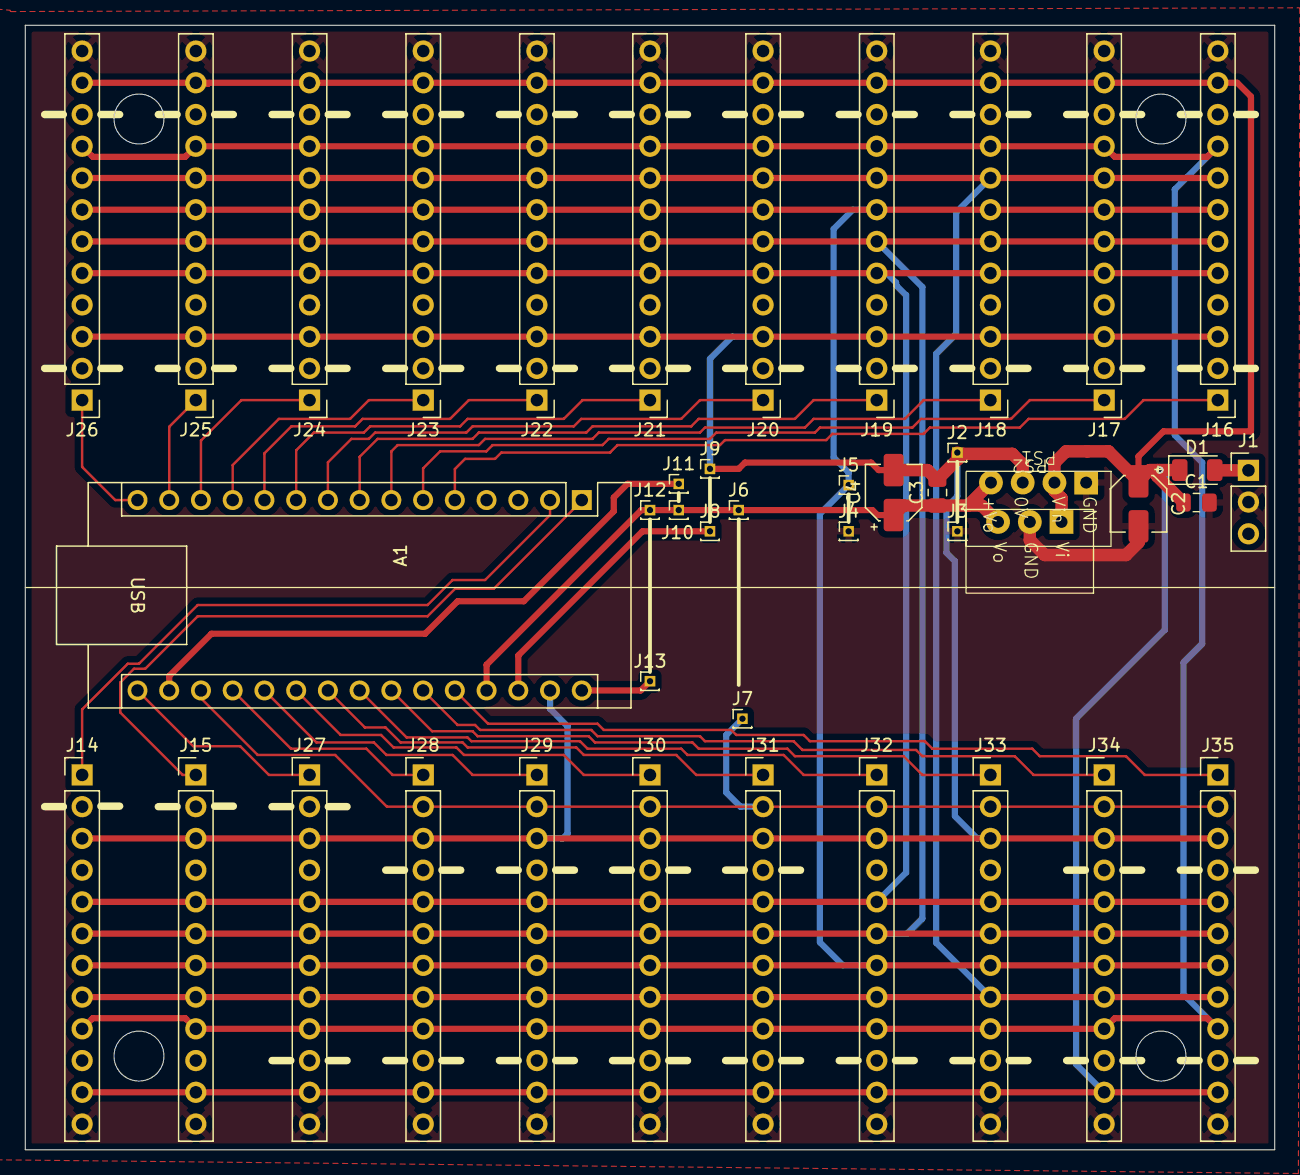
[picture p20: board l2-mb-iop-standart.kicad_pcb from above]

Board: 2 copper layers, 100.0 x 90.0 mm, 43 parts (0 on the bottom side), 35 nets.

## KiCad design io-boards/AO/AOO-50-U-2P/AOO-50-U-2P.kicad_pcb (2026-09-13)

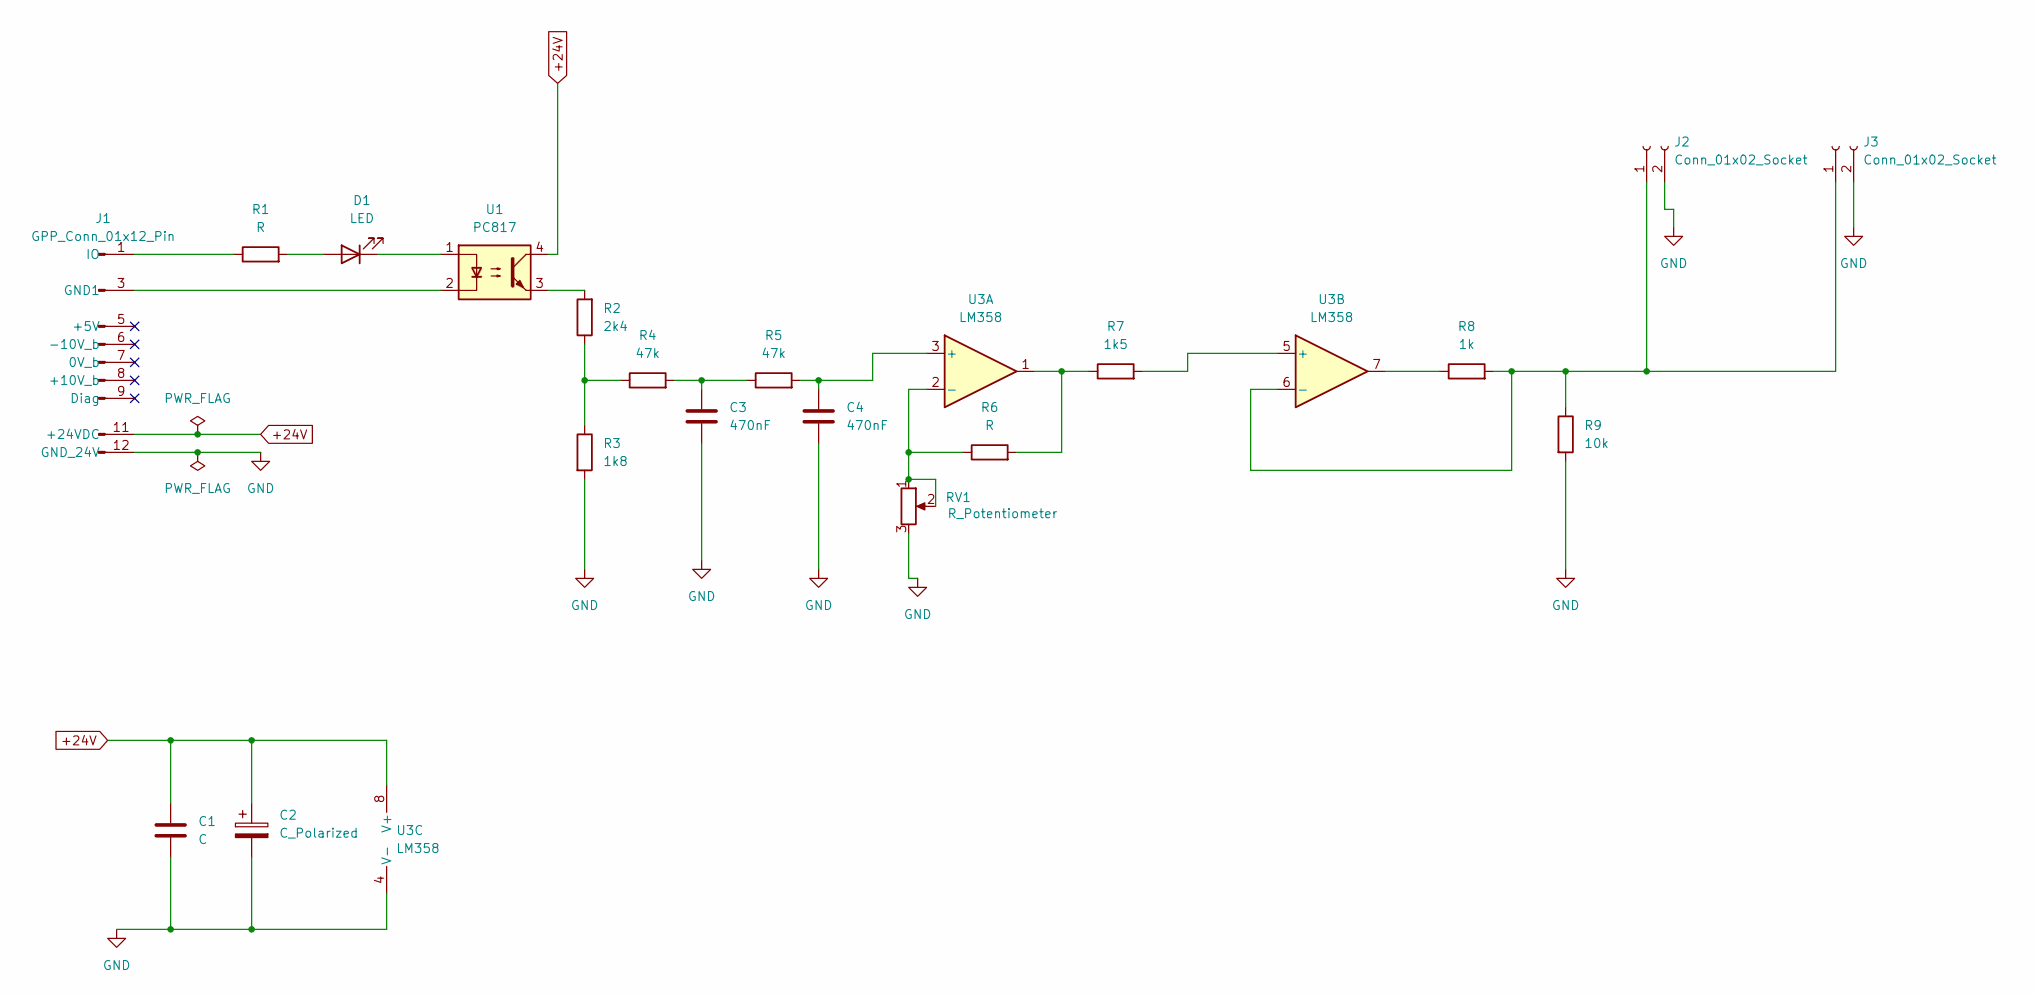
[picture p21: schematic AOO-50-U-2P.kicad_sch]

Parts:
C1: C; C_Disc_D4.7mm_W2.5mm_P5.00mm
C2: C_Polarized; CP_Radial_D4.0mm_P2.00mm
C3, C4: 470nF; C_Disc_D6.0mm_W2.5mm_P5.00mm
D1: LED; LED_D3.0mm
J1: GPP_Conn_01x12_Pin; IO_GPP_PinHeader_1x12_P2.54mm_Horizontal
J2: Conn_01x02_Socket; KF141x_SMD
J3: Conn_01x02_Socket; PinSocket_1x02_P2.54mm_Horizontal
R1, R6: R; R_Axial_DIN0204_L3.6mm_D1.6mm_P5.08mm_Horizontal
R2: 2k4; R_Axial_DIN0204_L3.6mm_D1.6mm_P5.08mm_Horizontal
R3: 1k8; R_Axial_DIN0204_L3.6mm_D1.6mm_P5.08mm_Horizontal
R4, R5: 47k; R_Axial_DIN0204_L3.6mm_D1.6mm_P5.08mm_Horizontal
R7: 1k5; R_Axial_DIN0204_L3.6mm_D1.6mm_P5.08mm_Horizontal
R8: 1k; R_Axial_DIN0204_L3.6mm_D1.6mm_P5.08mm_Horizontal
R9: 10k; R_Axial_DIN0204_L3.6mm_D1.6mm_P5.08mm_Horizontal
RV1: R_Potentiometer; Potentiometer_Vishay_148-149_Single_Vertical
U1: PC817; DIP-4_W7.62mm_SMDSocket_SmallPads
U3: LM358; DIP-8_W7.62mm

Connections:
+24V: C1.1, C2.1, J1.11 (+24VDC), U1.4, U3.8 (V+)
GND: C1.2, C2.2, C3.2, C4.2, J1.12 (GND_24V), J2.2, J3.2, R3.2, R9.2, RV1.3, U3.4 (V-)
unnamed: C3.1, R4.2, R5.1
unnamed: D1.2 (A), R1.2
unnamed: D1.1 (K), U1.1
unnamed: J1.3 (GND1), U1.2
unnamed: J1.1 (IO), R1.1
unnamed: J2.1, J3.1, R8.2, R9.1, U3.6 (-)
unnamed: R2.1, R3.1, R4.1
unnamed: R2.2, U1.3
unnamed: R6.2, R7.1, U3.1
unnamed: R8.1, U3.7
unnamed: C4.1, R5.2, U3.3 (+)
unnamed: R6.1, RV1.1, RV1.2, U3.2 (-)
unnamed: R7.2, U3.5 (+)

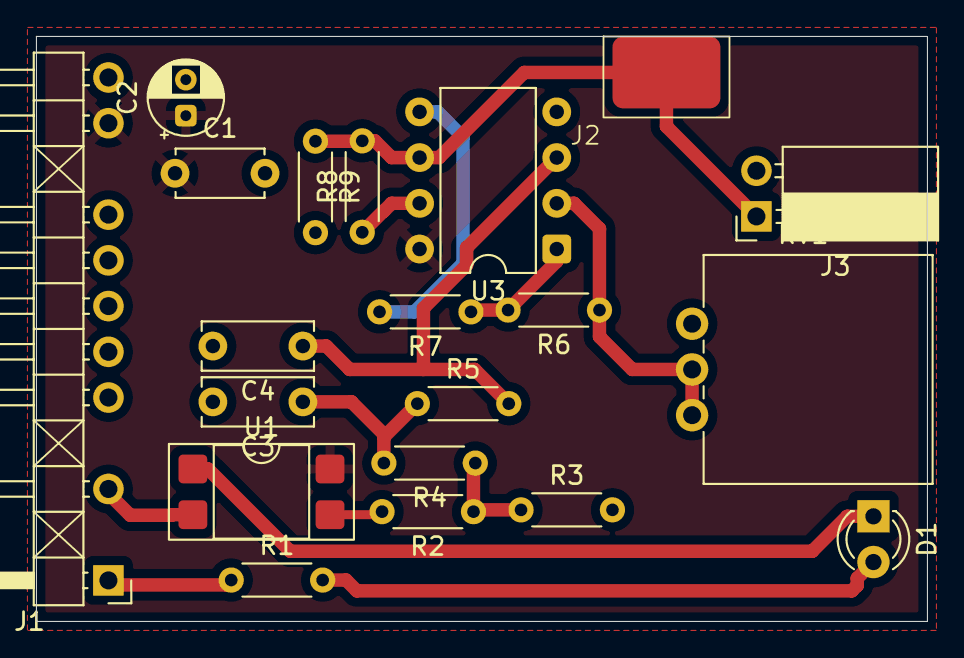
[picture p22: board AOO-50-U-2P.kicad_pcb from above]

Board: 2 copper layers, 49.5 x 32.5 mm, 20 parts (0 on the bottom side), 15 nets.

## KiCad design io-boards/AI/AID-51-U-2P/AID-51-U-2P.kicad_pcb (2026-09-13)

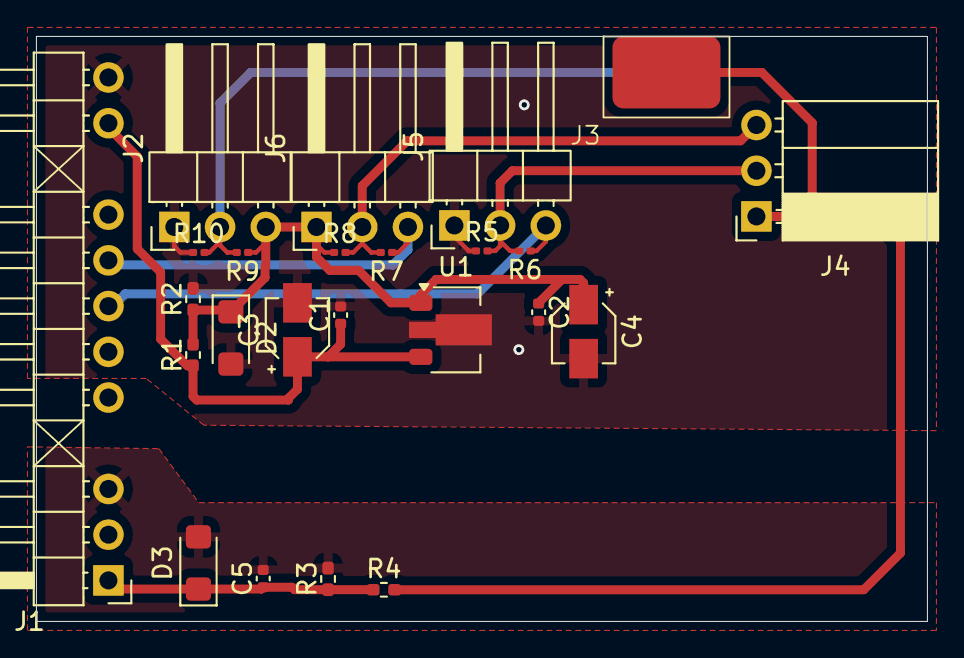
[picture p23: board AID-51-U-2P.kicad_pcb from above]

Board: 2 copper layers, 49.5 x 32.5 mm, 24 parts (0 on the bottom side), 11 nets.

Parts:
C1, C2: 100nF; C_0402_1005Metric
C3: 10uf 50V; CP_Elec_3x5.3
C4: 10uF 50V; CP_Elec_3x5.3
C5: 10nF; C_0402_1005Metric
D2: 11V - BZD27C11P; D_SMF
D3: 5V1 - BZD27C5V1P; D_SMF
J1: AIP_Conn_01x12_Pin; IO_AIP_PinHeader_1x12_P2.54mm_Horizontal
J2, J5, J6: Conn_01x03_Pin; PinHeader_1x03_P2.54mm_Horizontal
J3: Conn_01x02_Socket; KF141x_SMD
J4: Conn_01x03_Socket; PinSocket_1x03_P2.54mm_Horizontal
R1: 2k2; R_0402_1005Metric_Pad0.72x0.64mm_HandSolder
R2: 1k8; R_0402_1005Metric_Pad0.72x0.64mm_HandSolder
R3, R4: 5k1; R_0402_1005Metric_Pad0.72x0.64mm_HandSolder
R5, R6, R7, R8, R9, R10: j; R_0201_0603Metric
U1: L78L10_SOT89; SOT-89-3

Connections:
GND: C1.2, C2.2, C3.2, C4.2, D2.2 (A), J1.12 (GND_24V), J2.1, J5.1, R2.2, R5.1, R10.1, U1.2 (GND)
GND1: C5.2, D3.2 (A), J1.3 (GND1), R3.2
unnamed: C2.1, C4.1, D2.1 (K), J2.3, J6.1, R1.2, R2.1, R8.1, R9.1, U1.1 (OUT)
unnamed: C5.1, D3.1 (K), J1.1 (IO), R3.1, R4.1
unnamed: J1.7 (0V_b), J5.3, R6.1
unnamed: J1.8 (+10V_b), J6.3, R7.1
unnamed: C1.1, C3.1, J1.11 (+24VDC), R1.1, U1.3 (IN)
unnamed: J2.2, J3.2, R9.2, R10.2
unnamed: J3.1, J4.1, R4.2
unnamed: J4.2, J5.2, R5.2, R6.2
unnamed: J4.3, J6.2, R7.2, R8.2

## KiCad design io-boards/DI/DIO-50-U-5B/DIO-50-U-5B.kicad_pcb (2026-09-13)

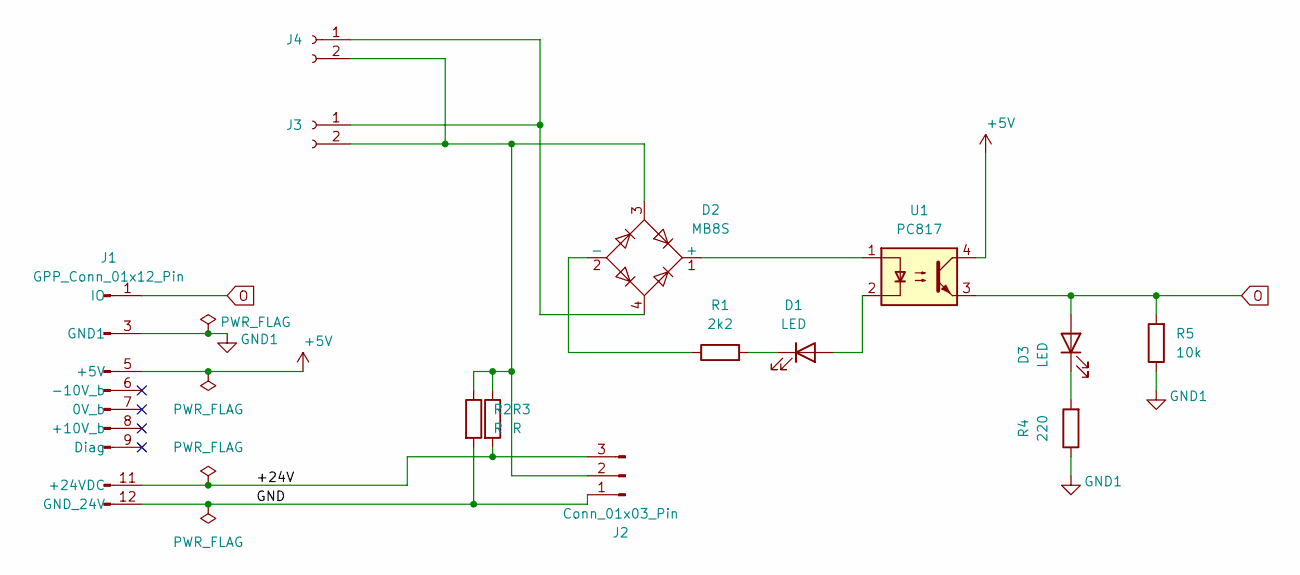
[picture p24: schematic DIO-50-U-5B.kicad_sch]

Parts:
D1, D3: LED; LED_0402_1005Metric_Pad0.77x0.64mm_HandSolder
D2: MB8S; OnSemi_751EP_SOIC-4_3.9x4.725mm_P2.54mm
J1: GPP_Conn_01x12_Pin; IO_GPP_PinHeader_1x12_P2.54mm_Horizontal
J2: Conn_01x03_Pin; PinHeader_1x03_P2.54mm_Horizontal
J3: Conn_01x02_Socket; KF141x_SMD
J4: Conn_01x02_Socket; PinSocket_1x02_P2.54mm_Horizontal
R1: 2k2; R_0402_1005Metric_Pad0.72x0.64mm_HandSolder
R2, R3: R; R_0201_0603Metric_Pad0.64x0.40mm_HandSolder
R4: 220; R_0402_1005Metric_Pad0.72x0.64mm_HandSolder
R5: 10k; R_0402_1005Metric_Pad0.72x0.64mm_HandSolder
U1: PC817; DIP-4_W7.62mm_SMDSocket_SmallPads

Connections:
+5V: J1.5 (+5V), U1.4
/+24V: J1.11 (+24VDC), J2.3, R3.2
/GND: J1.12 (GND_24V), J2.1, R2.2
GND1: J1.3 (GND1), R4.1, R5.1
unnamed: D1.2 (A), U1.2
unnamed: D1.1 (K), R1.2
unnamed: D2.1 (+), U1.1
unnamed: D2.2 (-), R1.1
unnamed: D3.1 (K), R4.2
unnamed: D2.3, J2.2, J3.2, J4.2, R2.1, R3.1
unnamed: D2.4, J3.1, J4.1
O: D3.2 (A), J1.1 (IO), R5.2, U1.3

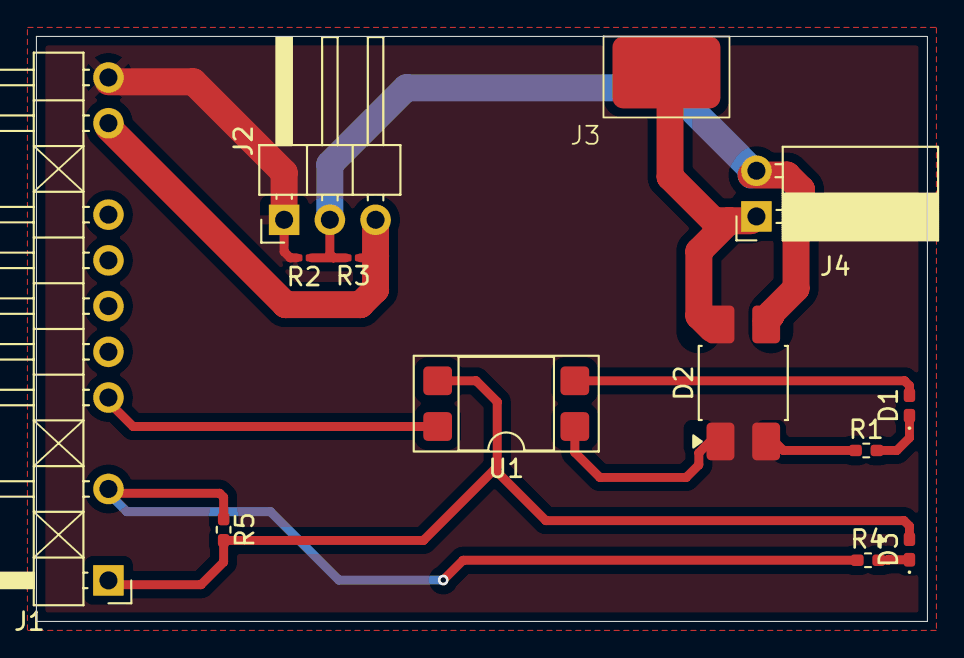
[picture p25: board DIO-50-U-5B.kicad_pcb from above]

Board: 2 copper layers, 49.5 x 32.5 mm, 13 parts (0 on the bottom side), 12 nets.

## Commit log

2025-10-10 Structure added
    [DIN-rail.FCStd, PCB-adapter-45.FCStd, PCB-adapter-45.stl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]
2025-10-11 Added IO sockets. Diference from usual female pin header is that on silkscreen layer marked placer for plugs
2025-10-11 Added IO pin header connection for IO boards. Removed holes for compatability.
2025-10-12 Added symbols: connectors and sockets that are linked to corresponding footprints.
2025-10-12 Added boards outline drawing with dimensions.
    [Dimentions_of_boards.dxf]
2025-10-16 Changed dimensions of MBs.
    [l2-mb-iop-standart.kicad_pcb, l2-mb-iop-standart.kicad_sch, mb-iob-l2.kicad_pcb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]
2025-10-17 Added DCDC to L2-MB-IOP as an option so it can be used stanalone without L0 and L1.
    [l2-mb-iop-standart.kicad_sch]
2025-10-19 Started routing L2-MB pcb.
    [#Dimentions_of_boards.dxf, l2-mb-iop-standart.kicad_pcb]
2025-10-20 Trying to place all jumpers on board.
    [#Dimentions_of_boards.dxf, l2-mb-iop-standart.kicad_pcb, l2-mb-iop-standart.kicad_sch]
2025-10-24 Trying to place everithing on board
    [l2-mb-iop-standart.kicad_pcb, l2-mb-iop-standart.kicad_sch]
2025-10-26 Board first version
    [#Dimentions_of_boards.dxf, Dimentions_of_boards.dxf, cover-CoverPad.stl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]
2025-10-29 Started first DO board
    [DON-50-U-5N.kicad_pcb, DON-50-U-5N.kicad_sch, l2-mb-iop-standart.kicad_pcb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]
2025-11-02 Created DIO board.
    [DIO-5-0-U-5B.kicad_pcb, DIO-5-0-U-5B.kicad_sch, l2-mb-iop-standart.kicad_sch]
2025-11-02 Created step for KF141.
    [KF141_Cover.step]
2025-12-07 Added Analog Output board for DIP components for testing
    [AOO-50-U-2P.kicad_pcb, AOO-50-U-2P.kicad_sch, DIO-5-0-U-5B-Edge_Cuts.dxf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]
2026-08-10 Board nomenclature was changed. Some changes in Boards.
    [#Dimentions_of_boards.dxf, DIO-50-U-5B-Edge_Cuts.dxf, DIO-50-U-5B-F_Silkscreen.dxf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]
2026-08-14 New DO added.
    [#Dimentions_of_boards.dxf, DOO-50-U-5N.kicad_pcb, DOO-50-U-5N.kicad_sch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]
2026-08-14 Started new AI board
    [AID-51-U-2P.kicad_pcb, AID-51-U-2P.kicad_sch]
2026-08-17 AI board has been finnished.
    [AID-51-U-2P.kicad_pcb, AID-51-U-2P.kicad_sch]
2026-08-17 Made some changes on IO boards prepared gerber files
    [l2-mb-iop-standart-B_Cu.gbr, l2-mb-iop-standart-B_Mask.gbr, l2-mb-iop-standart-B_Paste.gbr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]
2026-09-13 Made some corrections after assembling of prototype PCBs
    [AID-51-U-2P.kicad_pcb, AID-51-U-2P.kicad_sch, AOO-50-U-2P.kicad_pcb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]
